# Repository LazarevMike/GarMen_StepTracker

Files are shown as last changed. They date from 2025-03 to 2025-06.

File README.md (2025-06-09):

# GarMen StepTracker

Code for step tracker for Embedded Mechatronic Systems (Autumn 2025) at UTS.  
Using ESP32S3 Mini and a custom-designed PCB in Altium Designer.
Programmed on C++ in Arduino IDE

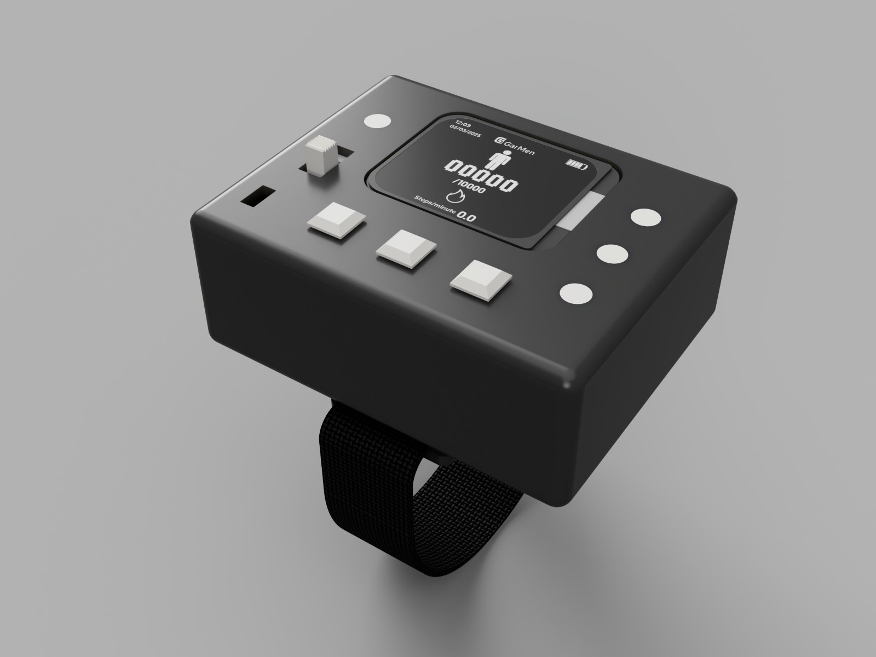
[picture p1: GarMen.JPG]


---

## 📌 Project Overview

This repository contains the Arduino code, simulation files and MCAD for the **Step Tracker System** using custom designed PCB, featuring ESP32S3 Mini ship and ADXL335 accelerometer.
The system counts steps, identifies walking pace, monitors heart rate and calories, and provides a clean user interface using an LCD screen.

---

## 🚀 Features

- **Step Counting**: Accurate detection using analog acceleration.
- **Pace Detection**: Classifies movement as Idle, Walk, or Run.
- **Heart Rate Monitoring**: Connects to BLE HR sensors (e.g., Polar H10).
- **Calories Burned Calculation**: Uses Zillman formula for accurate kcal estimation.
- **User Interface**:
  - LCD screen with different display modes (Steps / Stats).
  - Bluetooth connectivity status, battery level (optional), and timer.
- **Self-Test Protocol**: Validates ADXL335 using the ST pin.
- **Static Acceleration Calibration**: Calibrates ±X, ±Y, ±Z axes using known gravity values.
- **Dual Power Input**: Runs from DC barrel jack or battery.
- **Signal Conditioning**: Filters analog signals before ADC sampling.
- **BNC Output**: Clean analog Z-axis output for lab validation.

---

## 📦 Required Libraries

Before compiling and uploading, make sure the following Arduino libraries are installed:

| Library | Purpose |
|---|---|
| [`Adafruit GFX Library`](https://github.com/adafruit/Adafruit-GFX-Library) | Core graphics support for LCD display |
| [`Adafruit ST7735 and ST7789 Library`](https://github.com/adafruit/Adafruit-ST7735-Library) | Driver for 1.69" TFT LCD |
| [`TFT_eSPI`](https://github.com/Bodmer/TFT_eSPI) | High-performance display driver |
| [`NimBLE-Arduino`](https://github.com/h2zero/NimBLE-Arduino) | Efficient BLE (Bluetooth Low Energy) support for ESP32 |

> 🛠️ **Install these using**:  
> `Arduino IDE → Sketch → Include Library → Manage Libraries`  
> Or manually from GitHub into your `libraries` folder.

---

## 📁 Folder Structure

```text
code/Step_Tracker/
│
├── Step_Tracker.ino               # Main Arduino sketch (initializes and runs StepTracker)
│
├── StepTracker.cpp/.h            # Core system controller (coordinates sensors, UI, and states)
├── StepCounter.cpp/.h            # Step detection, step rate, and pace estimation
├── CaloriesCalculator.cpp/.h     # Calorie calculation based on heart rate and step data
├── HeartRateMonitor.cpp/.h       # BLE heart rate monitor interface and data parser
├── ADXL335.cpp/.h                # Accelerometer driver (data reading, calibration, self-test)
├── Clock.cpp/.h                  # Tracks elapsed runtime using millis()
│
├── Button.cpp/.h                 # Debounced button input handler
├── Led.cpp/.h                    # LED driver with state control 
├── Lcd.cpp/.h                    # LCD display manager using Adafruit ST7789
├── UserInterface.cpp/.h          # High-level UI controller (button handling, display updates)
├── DisplayState.h                # Enum for UI display modes (Steps, Stats, Calibration, SelfTest)
└── media/                        # Folder for images, fonts, or other display assets

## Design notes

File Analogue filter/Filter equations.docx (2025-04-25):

# Solving second order analogue filter

Second order polynomial:

P(s)= s^2 +1.414s+1

Coefficients:

a_1 =1.414, a_0 =1

Substitutions:

s=j2πω, ωc=2πfc, a_1 =1/Q, √(a_0)=FSF

Hence,

Q=0.707, FSF=1

For filter with gain K=1, equations from Texas Instruments:

FSF×f_c =1/(2πRC√(mn)), Q= (√(mn))/(m+1) where R_1 =mR, R_2 =R, C_1 =C, C_2 =nC

Solving for ratio of m and n

0.707= (√(mn))/(m+1)

0.707^2 =(mn)/(m^2 +2m+1)

0.707^2 m^2 +(2×0.707^2 -n)m+0.707^2 =0

m= (n-2×0.707^2 + √((2×0.707^2 -n)^2 -4×0.707^4))/(2×0.707^2)

The above gives us a graph for n to m ratio. Here we are free to pick any convenient ratio for the filter.

Choose n=2, m=1

Desired f_c =25Hz

Substituting in the equations from Texas Instruments to obtain C and R near standard values:

25= 1/(√2×2πRC)

As R is predetermined by internal resistance on each output of ADXL:

Choose R=32K (standard value)

C=1/(√2 ×25×2π×32×10^3)=0.1407×10^(-6) ≈0.15μF (standard value as well)

Results: R_1 =32K, R_2 =32K, C_1 =0.15μF, C_2 =0.33μF

Check the actual cutoff frequency f_c

f_c = 1/(2π×32×10^3 ×√(0.15×0.33)×10^(-6))=22.35 Hz - a bit lower than expected f_c

Let’s adjust value for R_2 as we can choose it freely as long as Q stays around 0.707

Try: R_2 =27K

Check for Q

Q= (√(32×10^3 ×27×10^3 ×0.15×10^(-6) ×0.33×10^(-6)))/((32+27)×10^3 ×0.15×10^(-6))=0.739 (expected 0.707)

As Q is so far off, behaviour of filter might be altered. That calls for reworking coefficients m and n

Choose m=3.95, n=3.1 , since it is easy to find capacitors for such ratio n

As it is predetermined by ADXL that R_1 =32K

R_2 =(R_1)/m=(32×10^3)/3.95 =8.10 ×10^3 ≈8.2K (table value)

Compute actual m

m=32/8.2=3.90

Now, calculate C for chosen f_c

C=1/(√(3.1×3.90) ×25×2π×8.2×10^3)=2.23×10^(-7) ≈0.22μF (table value)

C_2 =nC=0.22×10^(-6) ×3.1=0.682×10^(-6) ≈0.68μF (table value)

Results: R_1 =32K, R_2 =8.2K, C_1 =0.22μF, C_2 =0.68μF

Check for actual f_c

f_c = 1/(2π×√(32×8.2×0.22×0.68)×10^3 ×10^(-6))=25.4Hz

Taking into account tolerance of 15% on R_1 , f_c is expected to be within 23.7 – 27.6Hz

Finally, check for actual Q

Q= (√(32×10^3 ×8.2×10^3 ×0.22×10^(-6) ×0.68×10^(-6)))/((32+8.2)×10^3 ×0.22×10^(-6))= 0.708 - very close to expected 0.707

Taking into account tolerance of 15% on R_1 , Q is expected to be within 0.679 – 0.742

To negate very low tolerance on R_1 , it was decided to not use the resistor from ADXL and rather place another 32K resistor with higher tolerance, separated from ADXL using buffer amplifier.

Appendix:

A. Graph for n and m

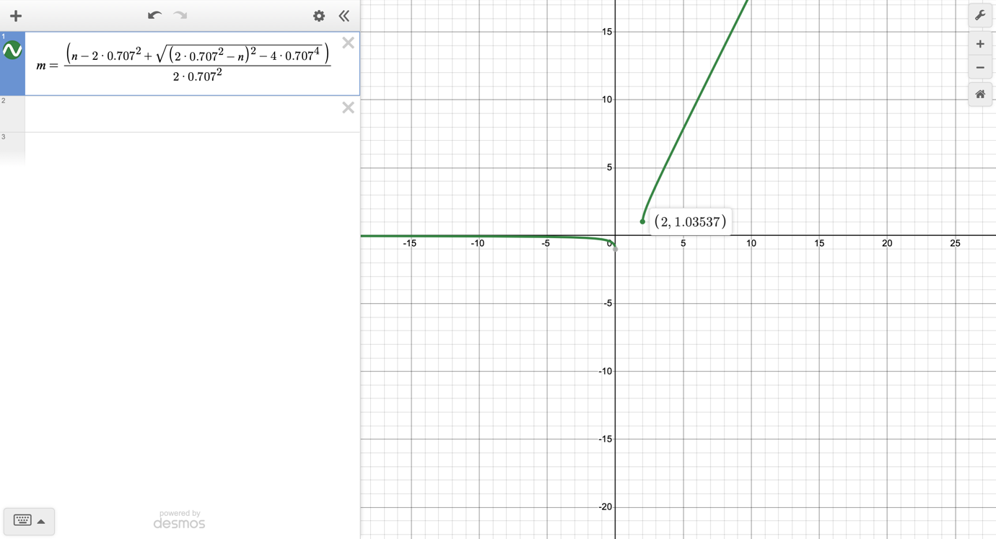
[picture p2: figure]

B. Another trial for m and n:

Choose n=2.2, m = 1.87

Hence R1 = 32K (from datasheet)

R2 = 17.65 ~ 18K

Calculate C for cutoff frequency 25Hz

C = 0.17 microF – not table value. Try again

Can be used if fc is changed to 29Hz or 18-19Hz

C. Calculations brief (for slides)  Second order polynomial:

P(s)= s^2 +1.414s+1

From the coefficients of the polynomial:

Q=0.707, FSF=1

For filter with gain K=1, equations from Texas Instruments:

FSF×f_c =1/(2πRC√(mn)), Q= (√(mn))/(m+1) where R_1 =mR, R_2 =R, C_1 =C, C_2 =nC

Solving for ratio of m and n we get the graph for m

m= (n-2×0.707^2 + √((2×0.707^2 -n)^2 -4×0.707^4))/(2×0.707^2)

Choose m=3.95, n=3.1 , since it is easy to find capacitors for such ratio n

After choosing R_1 =32K and calculating the rest of components:

R_1 =32K, R_2 =8.2K, C_1 =0.22μF, C_2 =0.68μF

Check for actual f_c

f_c = 1/(2π×√(32×8.2×0.22×0.68)×10^3 ×10^(-6))=25.4Hz

Finally, check for actual Q

Q= (√(32×10^3 ×8.2×10^3 ×0.22×10^(-6) ×0.68×10^(-6)))/((32+8.2)×10^3 ×0.22×10^(-6))= 0.708

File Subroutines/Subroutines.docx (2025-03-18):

Subroutines

Self-test subroutine

//While ADXL is stationary

Function ADXLSelfTest(ST_pin, X_pin, Y_pin, Z_pin) {

Write digital low to ST_pin

Pause 100ms

Record base values from X_pin, Y_pin, Z_pin

Write digital high to ST_pin

Pause 100ms

Record new values from X_pin, Y_pin, Z_pin

Write digital low to ST_pin

Calculate difference between base values and new values

If difference is greater than 0.3V (ADC value 4096 * 0.3/3.3 = 370) {

Output to serial “Self-test passed”

Return true

}

Else {

Output to serial “Self-test not passed”

Return false

}

}

Calibration subroutine

//After step tracker is mounted on the shoulder

Function ADXLCalibration(X_pin, Y_pin, Z_pin) {

Pause 5s

Record base values from X_pin, Y_pin, Z_pin

Pause 5s

Blink LEDs to indicate that used should start walking

//While user is walking

For the next 10s {

Record maximum values from X_pin, Y_pin, Z_pin

}

Blink LEDs twice to indicate that calibration is complete

Subtract base values from maximum values to get differences

Divide difference values by 1.4

Return an array of base values and difference values

//These values should be used in the main script for comparison to detect steps

Step tracker subroutine

//After calibration is complete

Function stepTracking()

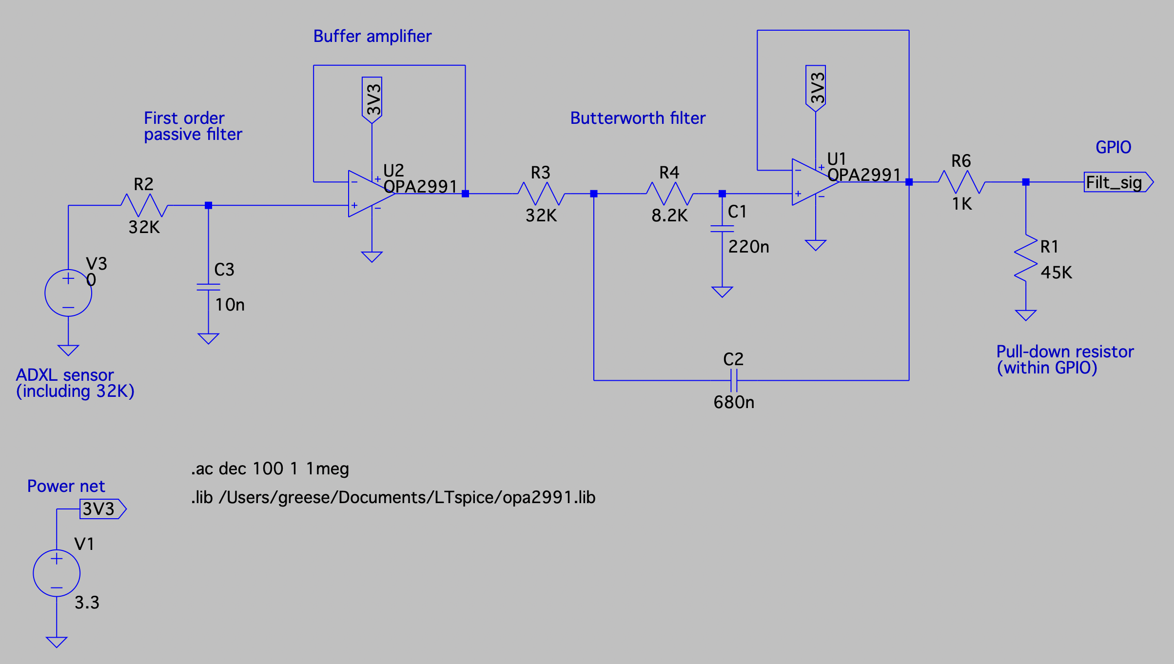
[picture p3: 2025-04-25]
Simulations/Analogue filter/Real model/Schematic.png

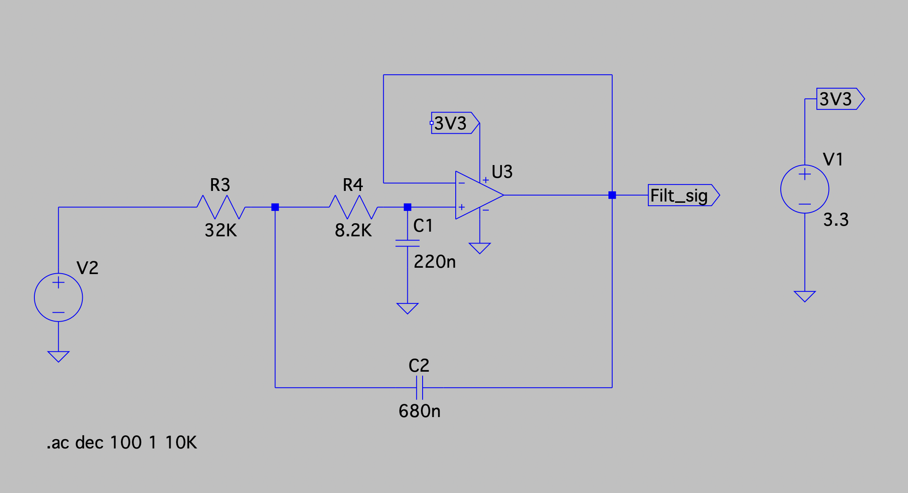
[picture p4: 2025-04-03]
Simulations/Analogue filter/Ideal model/Schematic.png

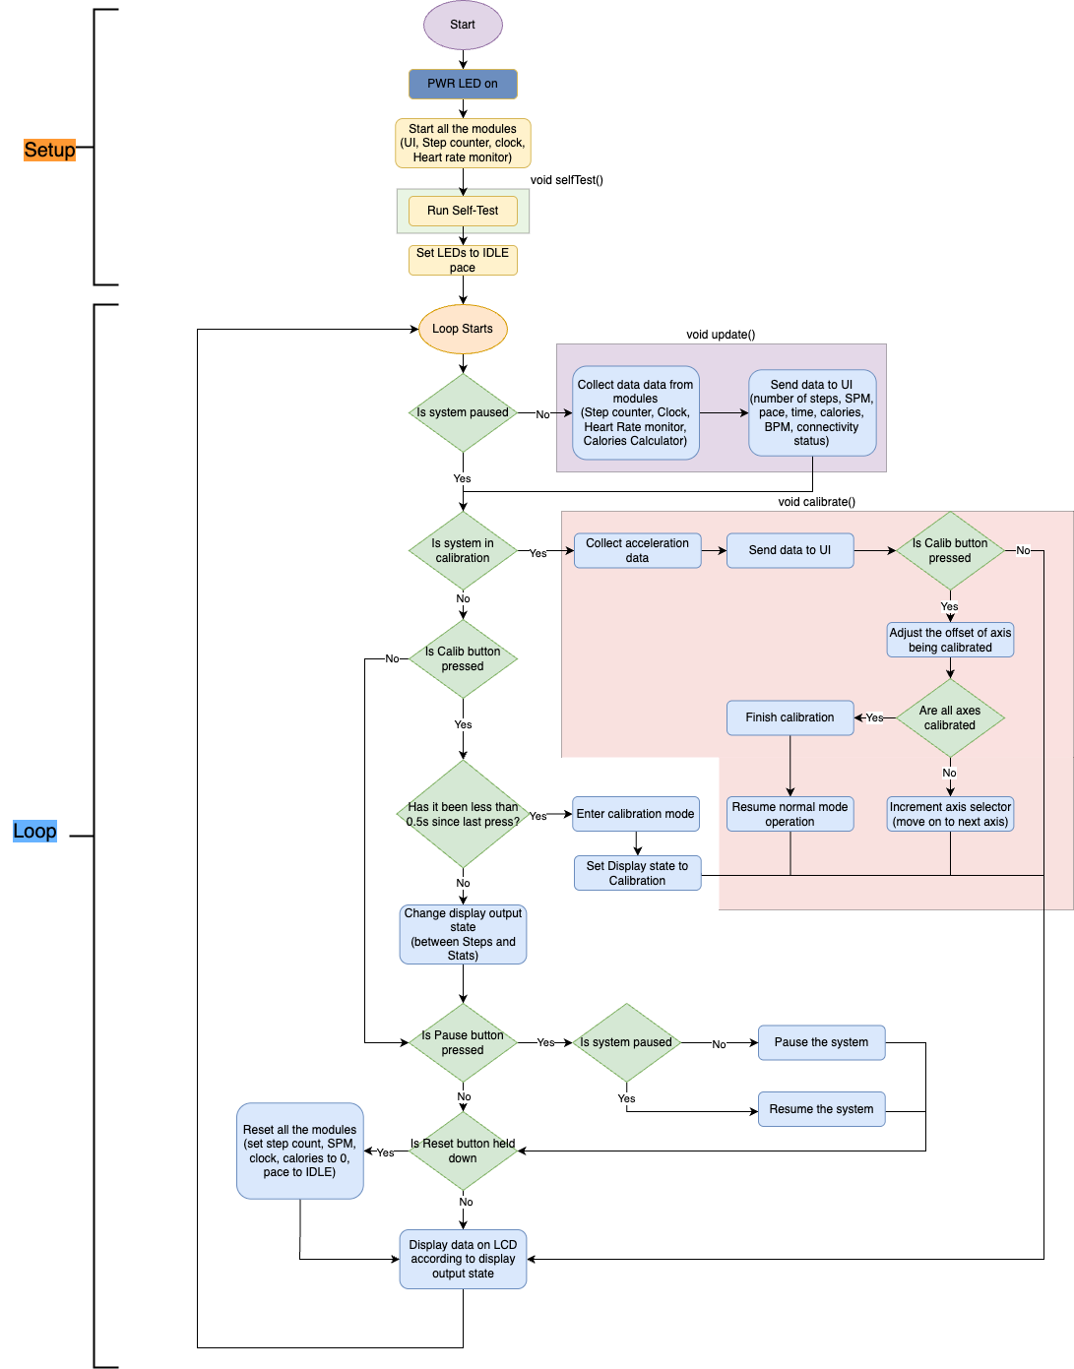
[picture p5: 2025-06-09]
Diagrams/Main flowchart.png

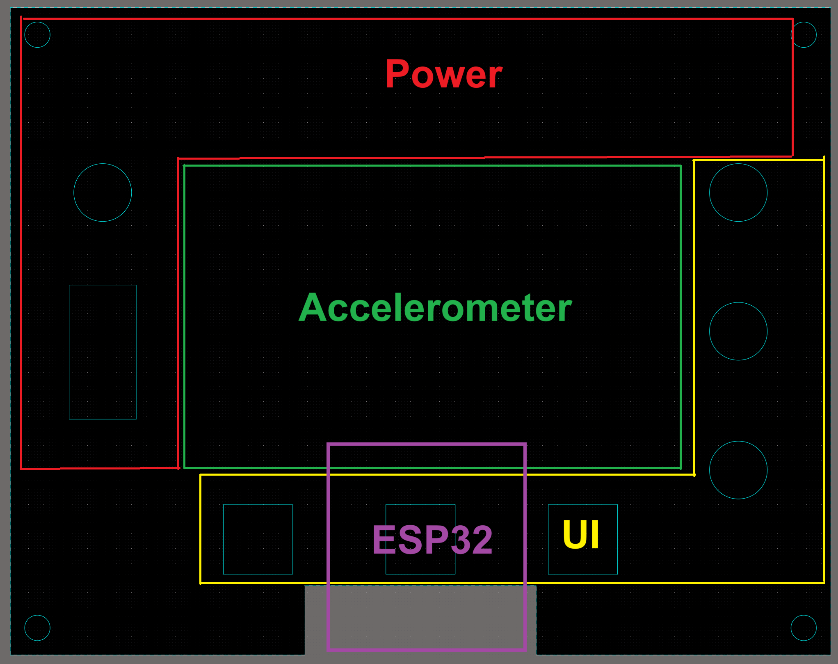
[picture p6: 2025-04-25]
Diagrams/PCB layout.png

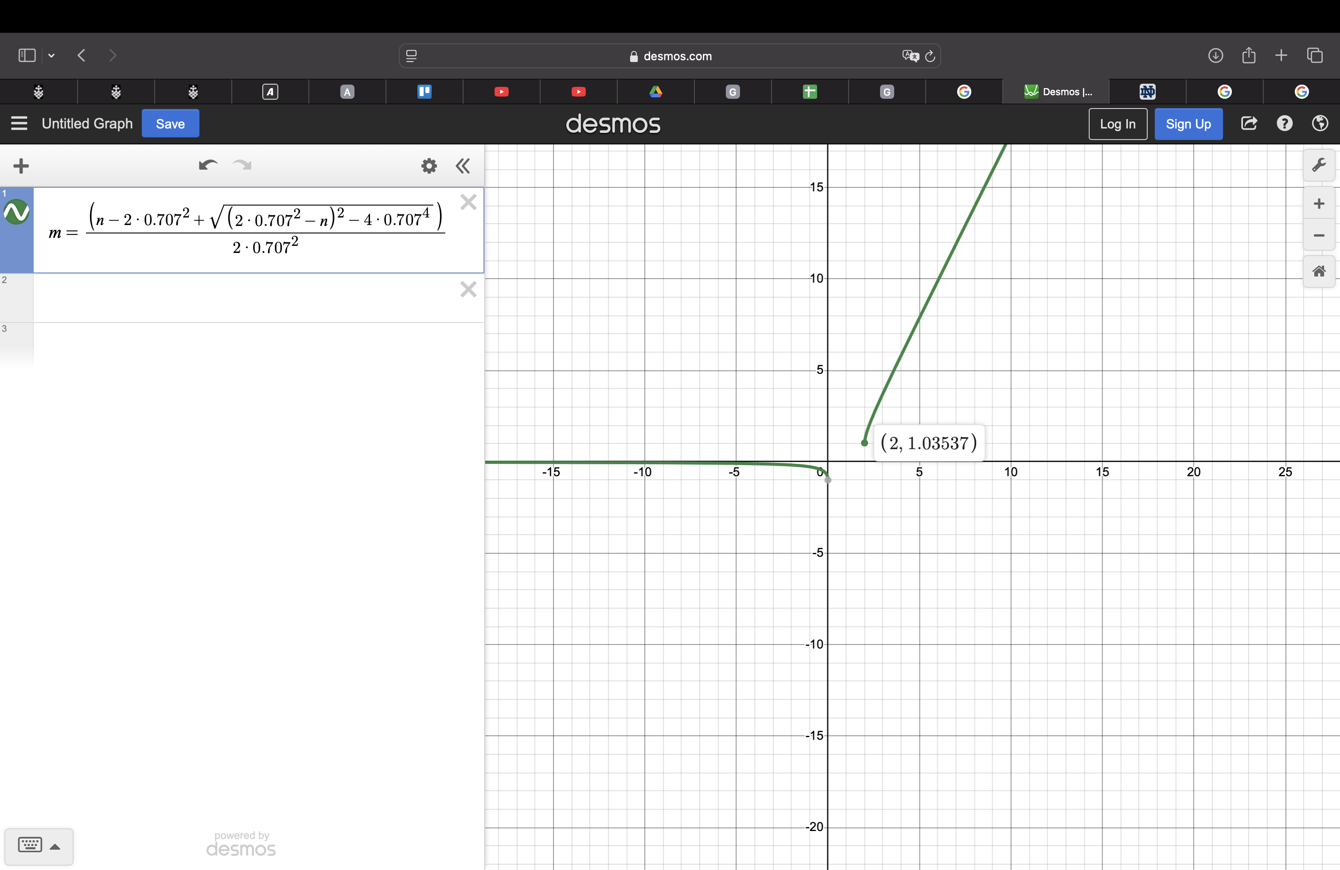
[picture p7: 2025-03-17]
Analogue filter/Graph.png

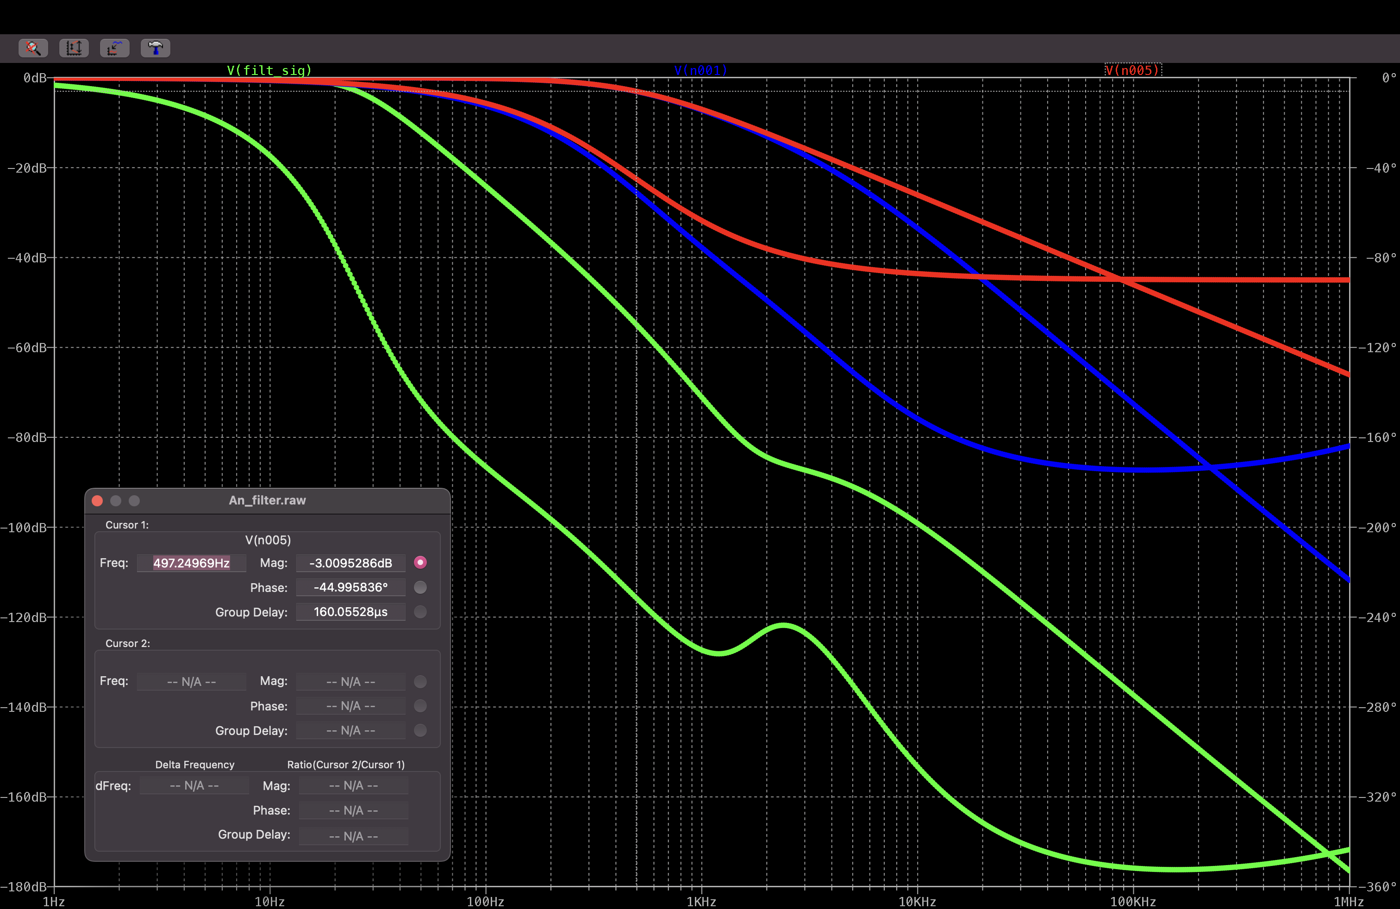
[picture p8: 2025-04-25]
Simulations/Analogue filter/Real model/Cutoff passive.png

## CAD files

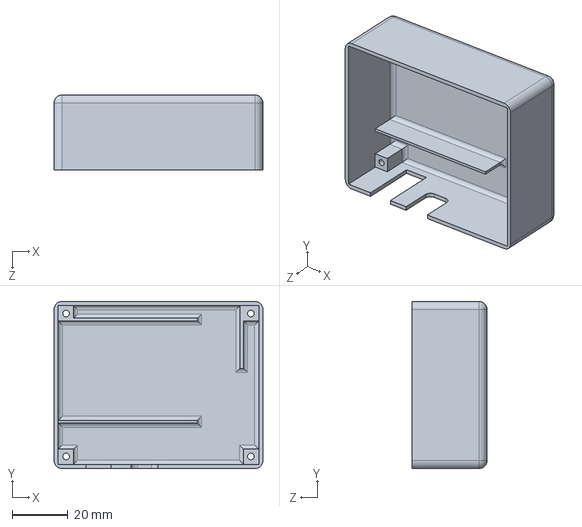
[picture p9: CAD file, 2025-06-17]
SolidWorks/Enclosure design/Main Case.SLDPRT
75.0 x 60.0 x 27.0 mm

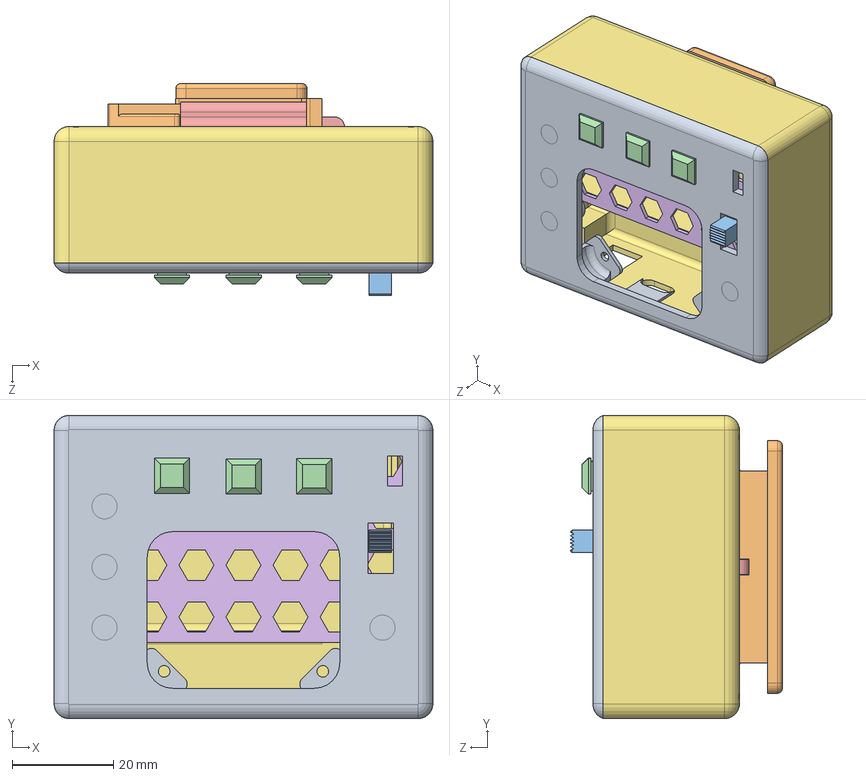
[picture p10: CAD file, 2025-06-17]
SolidWorks/Enclosure design/StepStracker Assembly.SLDASM
75.0 x 60.0 x 41.9 mm
Main Case
Mid plate
Universal connector
Button Cap x 3
Switch cap
Buckle
Top Cover

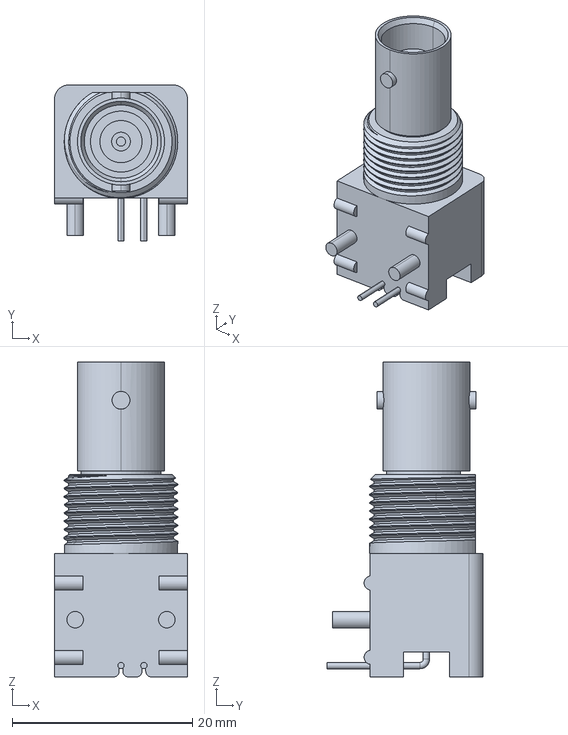
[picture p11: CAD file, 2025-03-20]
SolidWorks/Components/BNCConnector.stp
14.8 x 17.3 x 34.9 mm

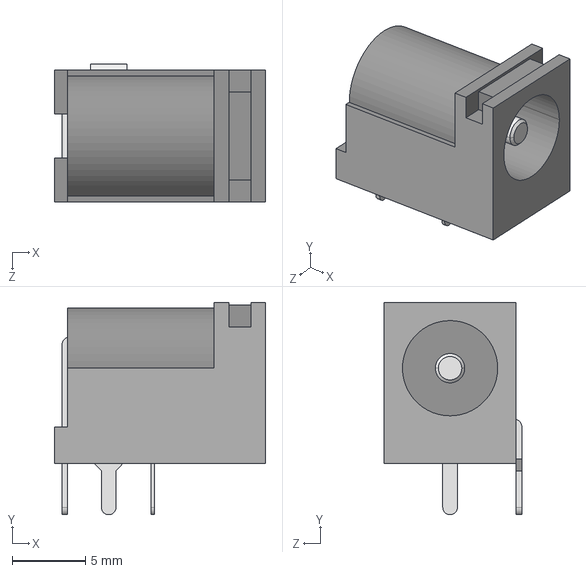
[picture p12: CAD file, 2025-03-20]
SolidWorks/Components/PowerBarrelConnector/BarrelJackConnector.step
14.4 x 14.5 x 9.40 mm

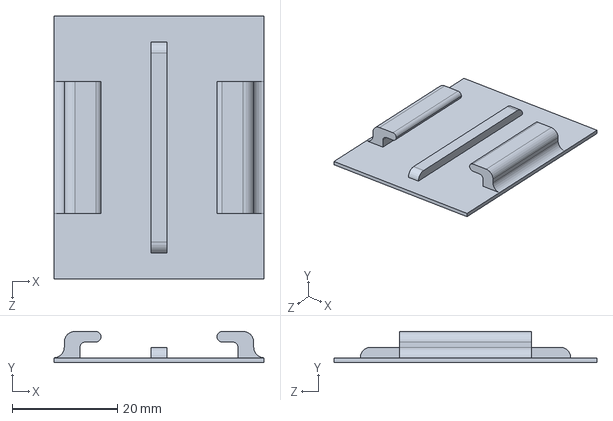
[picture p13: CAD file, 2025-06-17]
SolidWorks/Enclosure design/Universal connector.SLDPRT
39.9 x 5.90 x 49.9 mm

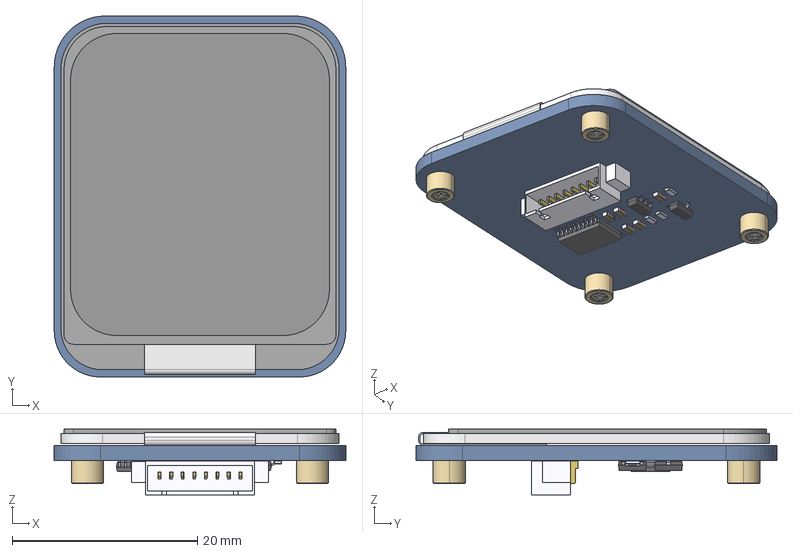
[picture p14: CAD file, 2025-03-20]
SolidWorks/Components/1_69inch-lcd-module.stp
31.5 x 39.0 x 7.11 mm
1_69INCH-240X280-LCD
1_69INCH_LCD_MODULE-PCBA
STUDS-M2XH2_5 x 4

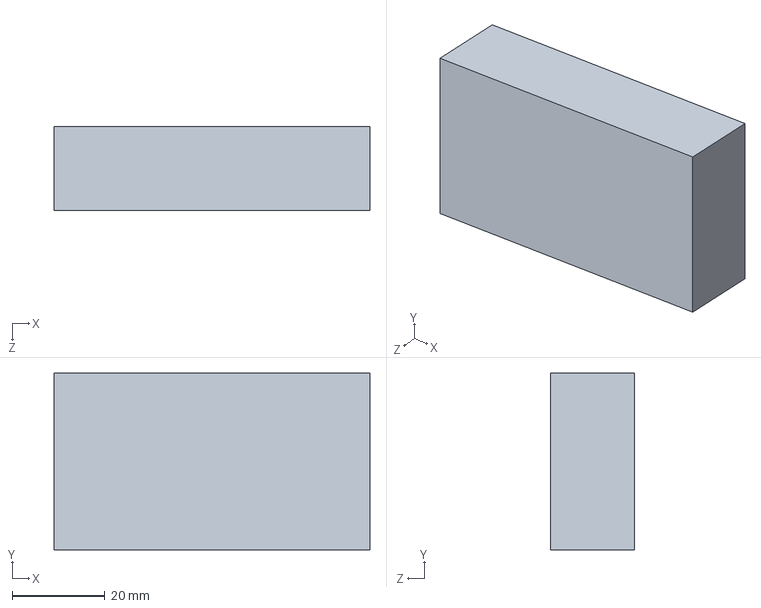
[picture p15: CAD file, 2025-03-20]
SolidWorks/Components/7.4VBattery.STEP
68.0 x 38.0 x 18.0 mm

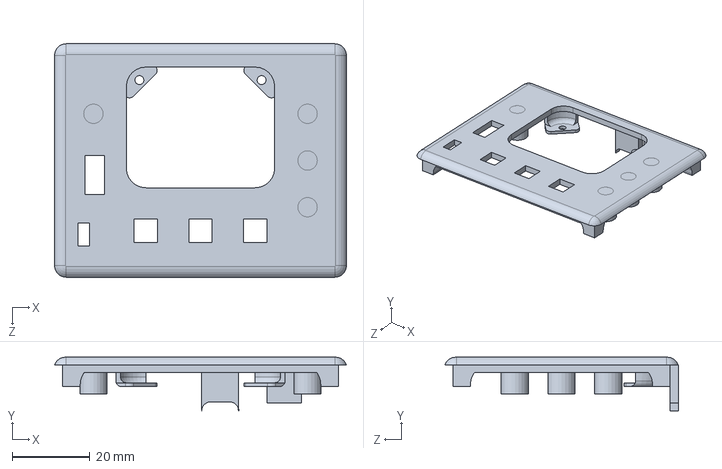
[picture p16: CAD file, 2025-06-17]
SolidWorks/Enclosure design/Top Cover.SLDPRT
75.0 x 13.8 x 60.0 mm

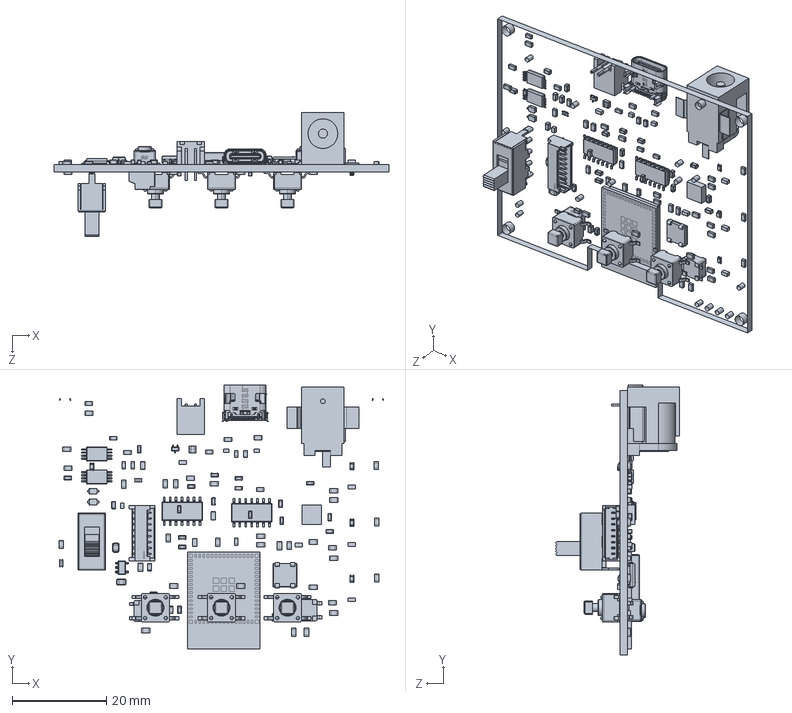
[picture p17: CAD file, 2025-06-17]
SolidWorks/Enclosure design/PCB_steptracker.SLDPRT
71.0 x 57.2 x 26.3 mm

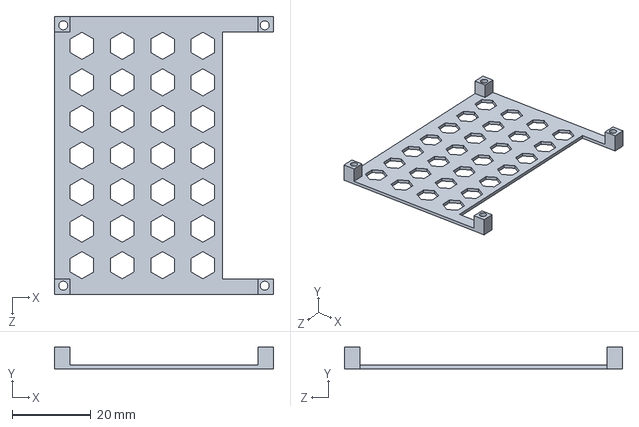
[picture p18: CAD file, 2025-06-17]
SolidWorks/Enclosure design/Mid plate.SLDPRT
55.8 x 5.50 x 70.8 mm

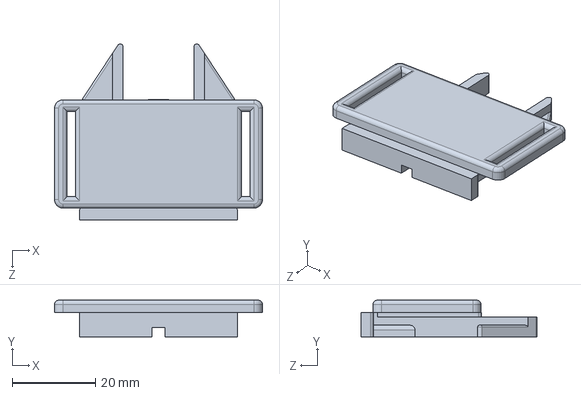
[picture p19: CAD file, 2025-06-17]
SolidWorks/Enclosure design/Buckle.SLDPRT
50.0 x 8.80 x 42.4 mm

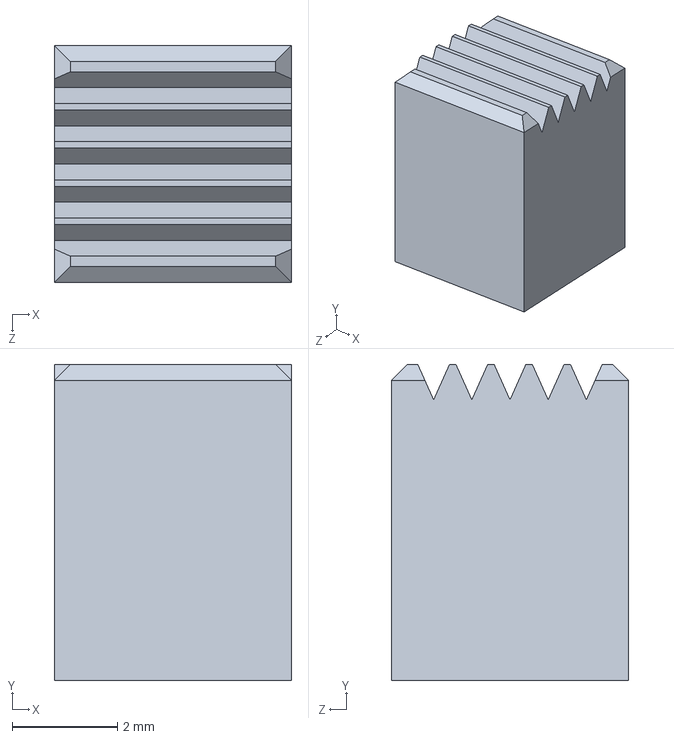
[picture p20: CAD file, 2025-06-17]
SolidWorks/Enclosure design/Switch cap.SLDPRT
4.50 x 6.00 x 4.50 mm

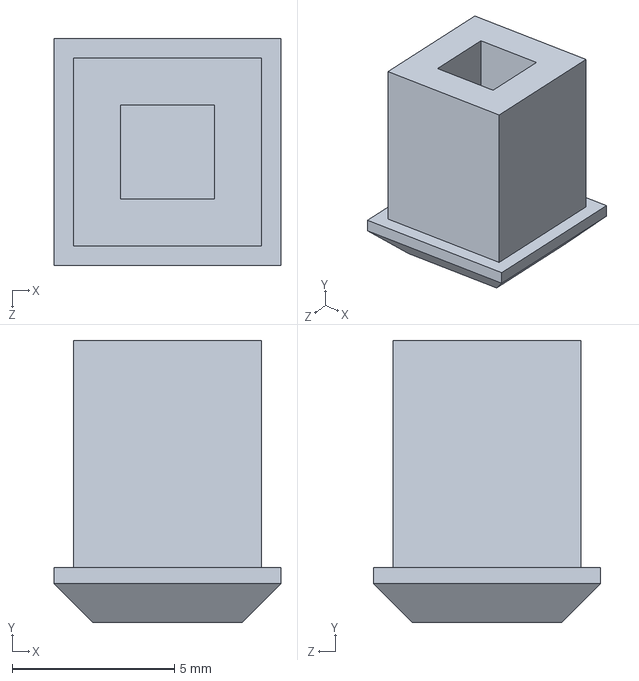
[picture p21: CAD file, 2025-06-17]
SolidWorks/Enclosure design/Button Cap.SLDPRT
7.00 x 8.70 x 7.00 mm

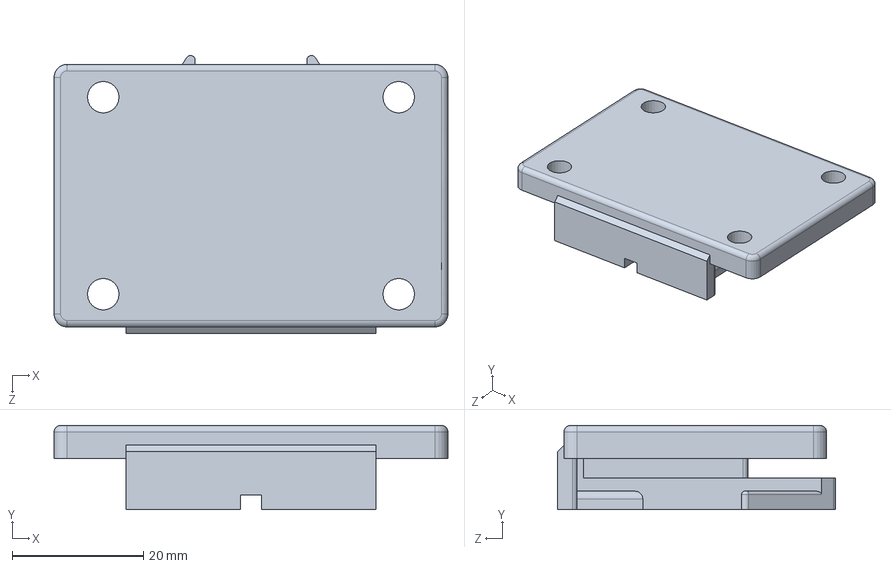
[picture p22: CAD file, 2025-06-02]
SolidWorks/Enclosure design/Mounting Buckle.SLDPRT
60.0 x 12.8 x 42.4 mm

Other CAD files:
SolidWorks/Enclosure design/1_69inch-lcd-module.SLDASM
SolidWorks/Enclosure design/PCB.SLDPRT
SolidWorks/Enclosure design/BNCConnector.SLDPRT
SolidWorks/Enclosure design/Battery.SLDPRT
SolidWorks/Components/Amphenol ICC (FCI)/20021221-00006C4LF.step
SolidWorks/Enclosure design/20021221-00006C4LF.SLDPRT
SolidWorks/Enclosure design/BarrelJackConnector.SLDPRT
SolidWorks/Enclosure design/Drawings/StepStracker Assembly.SLDDRW
SolidWorks/Enclosure design/Drawings/Top Cover.SLDDRW

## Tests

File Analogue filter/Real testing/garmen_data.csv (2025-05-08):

#Digilent WaveForms Network Analyzer - Bode
#Device Name: Discovery3
#Serial Number: SN:210415BCB4FB
#Date Time: 2025-05-06 14:46:24.910
#Start: 10 Hz
#Stop: 5000 Hz
#Steps: 151
#Wavegen: Wavegen C1
#Amplification: 1 X
#Settle: 10 ms
#MinPeriods: 16
#Channel: Channel 1
#Range: 5.19526 V
#Offset: 0.000309259 V
#Relative: no
Frequency (Hz) | Channel 1 Magnitude (dB)
10.00000000000001 | -0.2790251977869876
10.42300949424216 | -0.3030347177211944
10.86391269170621 | -0.3288130672549798
11.32346651302716 | -0.3580111438277471
11.80245989730152 | -0.3907812594463873
12.3017151564986 | -0.4284998944964031
12.82208938716475 | -0.4705111509610605
13.36447594184397 | -0.51956497628347
13.92980596274105 | -0.5751479845721507
14.51904998026008 | -0.6377328632870954
15.13321957916271 | -0.7093264217489261
15.77336913520643 | -0.7895391196473458
16.44059762524425 | -0.8792304550341733
17.1360505138936 | -0.9820678552899609
17.8609217200126 | -1.099874597101095
18.61645566636071 | -1.229982370940561
19.40394941596158 | -1.377710906480503
20.2247548988362 | -1.545833553534943
21.08028123292901 | -1.731537745959306
21.97199714321139 | -1.938381576497504
22.90143348311534 | -2.168495518726666
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

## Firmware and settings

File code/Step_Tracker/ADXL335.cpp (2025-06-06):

#include "ADXL335.h"
#include "Arduino.h"

ADXL335::ADXL335() : X_PIN_(8), Y_PIN_(13), Z_PIN_(9), ST_PIN_(34), 
X_ADC_OFFSET_(DEFALUT_ADC_OFFSET_), Y_ADC_OFFSET_(DEFALUT_ADC_OFFSET_), Z_ADC_OFFSET_(DEFALUT_ADC_OFFSET_) {
  pinMode(X_PIN_, INPUT);
  pinMode(Y_PIN_, INPUT);
  pinMode(Z_PIN_, INPUT);
  pinMode(ST_PIN_, OUTPUT);
  triggerSt(false);
}

int ADXL335::readX() {
  return analogRead(X_PIN_);
}

int ADXL335::readY() {
  return analogRead(Y_PIN_);
}

int ADXL335::readZ() {
  return analogRead(Z_PIN_);
}

void ADXL335::adjustOffsetX() {
  X_ADC_OFFSET_ = ((1.65 - SENSITIVITY_) / 3.3) * 4095 - readX();
}

void ADXL335::adjustOffsetY() {
  Y_ADC_OFFSET_ = ((1.65 + SENSITIVITY_) / 3.3) * 4095 - readY();
}
    
void ADXL335::adjustOffsetZ() {
  //Because adjusting on -g
  Z_ADC_OFFSET_ = ((1.65 - SENSITIVITY_) / 3.3) * 4095 - readZ();
}

float ADXL335::readAccelX() {
  // By hardware x is inverted
  return -convertADCtoAccel(readX() + X_ADC_OFFSET_);
}

float ADXL335::readAccelY() {
  return convertADCtoAccel(readY() + Y_ADC_OFFSET_);
}
    

float ADXL335::readAccelZ() {
  return convertADCtoAccel(readZ() + Z_ADC_OFFSET_);
}

void ADXL335::triggerSt(bool new_state) {
  st_state_ = new_state;
  //Inverted because by design st pin driver is active low
  digitalWrite(ST_PIN_, !st_state_);
}

bool ADXL335::selfTest() {
  float x1 = readAccelX();
  float y1 = readAccelY();
  float z1 = readAccelZ();
  triggerSt(true);
  delay(300);
  float x2 = readAccelX();
  float y2 = readAccelY();
  float z2 = readAccelZ();
  bool outcome = (x2 - x1 > -0.9 && y2 - y1 > 0.9 && z2 - z1 > 1.5);
  triggerSt(false);
  return outcome; 
}

bool ADXL335::getStState() {
  return st_state_;
}

float ADXL335::convertADCtoAccel(int adc_reading) {
  float voltage = (adc_reading)/4095.0 * 3.3;
  return (voltage - 1.65) / SENSITIVITY_;
}

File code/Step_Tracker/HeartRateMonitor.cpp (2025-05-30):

#include "HeartRateMonitor.h"

#define HEART_RATE_SERVICE_UUID        "180D"
#define HEART_RATE_MEASUREMENT_UUID   "2A37"

// Static pointer used to reference the class instance inside the static callback
HeartRateMonitor* HeartRateMonitor::instancePtr = nullptr;

/*
   Constructor initializes all internal state variables.
*/
HeartRateMonitor::HeartRateMonitor()
    : advDevice(nullptr),
      client(nullptr),
      latestBPM(0),
      newBPMAvailable(false),
      connected(false),
      doConnect(false) {}

/*
   Static notification callback for BLE heart rate data.
   Extracts BPM value from received data and stores it for printing in the main loop.
*/
void HeartRateMonitor::heartRateNotifyCB(NimBLERemoteCharacteristic* pChar, uint8_t* data, size_t length, bool isNotify) {
    if (length >= 2 && instancePtr != nullptr) {
        uint8_t flags = data[0];
        uint16_t bpm = (flags & 0x01) == 0
            ? data[1]                            // 8-bit BPM
            : (data[1] | (data[2] << 8));        // 16-bit BPM

        instancePtr->latestBPM = bpm;
        instancePtr->newBPMAvailable = true;
    }
}

/*
   Iterates over scan results to find a device advertising the Heart Rate Service.
   Stores reference to the matching device and stops scanning.
*/
void HeartRateMonitor::handleScanResults() {
    NimBLEScanResults results = NimBLEDevice::getScan()->getResults();

    for (int i = 0; i < results.getCount(); i++) {
        const NimBLEAdvertisedDevice* device = results.getDevice(i);

        if (device->isAdvertisingService(NimBLEUUID(HEART_RATE_SERVICE_UUID))) {
            Serial.println("Found device with Heart Rate Service.");
            advDevice = const_cast<NimBLEAdvertisedDevice*>(device);
            doConnect = true;
            NimBLEDevice::getScan()->stop();
            break;
        }
    }
}

/*
   Establishes BLE connection to the discovered device and subscribes to the
   heart rate characteristic for notifications.

   Returns true on successful connection and subscription, false otherwise.
*/
bool HeartRateMonitor::connect() {
    client = NimBLEDevice::createClient();

    if (!client->connect(advDevice)) {
        Serial.println("Failed to connect.");
        NimBLEDevice::deleteClient(client);
        return false;
    }

    Serial.println("Connected to device.");

    NimBLERemoteService* service = client->getService(HEART_RATE_SERVICE_UUID);
    if (!service) {
        Serial.println("Heart Rate Service not found.");
        client->disconnect();
        return false;
    }

    NimBLERemoteCharacteristic* characteristic = service->getCharacteristic(HEART_RATE_MEASUREMENT_UUID);
    if (!characteristic || !characteristic->canNotify()) {
        Serial.println("Heart Rate Characteristic not found or notifications not supported.");
        client->disconnect();
        return false;
    }

    if (!characteristic->subscribe(true, heartRateNotifyCB)) {
        Serial.println("Subscription to notifications failed.");
        client->disconnect();
        return false;
    }

    Serial.println("Subscribed to heart rate notifications.");
    connected = true;
    return true;
}

/*
   Initializes BLE stack, sets scan parameters, and starts scanning for BLE heart rate monitors.
   Also stores instance pointer to enable use of static callback.
*/
void HeartRateMonitor::begin() {
    instancePtr = this;

    NimBLEDevice::init("ESP32-HRM");

    NimBLEScan* scan = NimBLEDevice::getScan();
    scan->setActiveScan(true);     // Request additional advertising data
    scan->setInterval(45);         // How frequently to scan (in 0.625 ms units)
    scan->setWindow(15);           // How long to scan during each interval
    scan->start(0);                // 0 = scan indefinitely
}

/*
   This function should be called repeatedly in the main loop.
   It manages device discovery, connection attempts, and safely prints BPM when new data is available.
*/
void HeartRateMonitor::update() {
    // Continue processing scan results if not yet connected
    if (!connected) {
        handleScanResults();
    }

    // Attempt connection if a valid device was found
    if (doConnect && !connected) {
        doConnect = false;
        if (!connect()) {
            Serial.println("Connection failed. Restarting scan...");
            NimBLEDevice::getScan()->start(0);
        }
    }

    // Print latest heart rate reading, ensuring safe access to shared data
    if (newBPMAvailable) {
        noInterrupts();
        uint16_t bpmToPrint = latestBPM;
        newBPMAvailable = false;
        interrupts();

        Serial.printf("Heart Rate (BPM): %d\n", bpmToPrint);
    }
}

// Returns latest HR BPM
int HeartRateMonitor::getLatestBPM() const {
    return latestBPM;
}

// Returns connection status for HR monitor
bool HeartRateMonitor::isConnected() const {
    return connected;
}

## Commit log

2025-03-07 added Amphenol ICC (FCI) solidworks files
    [20021221-00006C4LF.step]
2025-03-07 Sourced main components 3D models
    [1_69inch-lcd-module.stp, BNCConnector.stp, BarrelJackConnector.step]
2025-03-07 Added sample code for Display and a python file to convert image to uint8_t image
2025-03-09 Battery model added
    [7.4VBattery.STEP]
2025-03-11 Updated diagram. New cut-off freq
2025-03-17 Analogue filter solved
2025-03-18 Added subroutines, changed R and C for filter
2025-03-20 Enclosure design updates
    [1_69inch-lcd-module.SLDASM, 1_69inch-lcd-module.stp, 20021221-00006C4LF.SLDPRT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]
2025-03-24 Reworked filter to accomodate for internal resistor of adxl
2025-03-24 Mechanical enclosure changes
    [Main Case.SLDPRT, Mid plate.SLDPRT, PCB.SLDPRT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]
2025-03-31 Added simulation results for self-test and analogue filter
2025-04-03 Enclosure changes
    [Buckle.SLDPRT, Main Case.SLDPRT, Mid plate.SLDPRT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]
2025-04-07 Added resistor to sim schematic
2025-04-25 solidworks files update
    [Main Case.SLDPRT, Top Cover.SLDPRT]
2025-05-08 Added some code file+ updated solidworks models
    [Main Case.SLDPRT, Mid plate.SLDPRT, Top Cover.SLDPRT]
2025-05-08 Added results for frequency sweep of analogue filter
    [garmen_data.csv]
2025-05-12 Added structure fot UI. Added classes for LEDs and Buttons with basic functionality
2025-05-12 Added buttons
2025-05-13 Updated buttons, added test code for buttons in UI
2025-05-15 enclosure design update
    [Buckle.SLDPRT, Button Cap.SLDPRT, Main Case.SLDPRT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]
2025-05-18 Finished Enclosure design
    [Switch cap.SLDPRT, Top Cover.SLDPRT]
2025-05-29 updated 3d models
    [Switch cap.SLDPRT, Top Cover.SLDPRT]
2025-05-30 added heart rate monitor code + edited solidworks models
    [Buckle.SLDPRT, Mid plate.SLDPRT, Switch cap.SLDPRT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]
2025-05-30 changed calories calculation + added comments to buttons
2025-05-30 made working UI
    Step screen ui, and HR and calories UI done
    [Buckle.SLDPRT, Button Cap.SLDPRT]
2025-06-02 minor changes enclosure CAD
    [Buckle.SLDPRT, Mounting Buckle.SLDPRT]
2025-06-02 added calibration screen
2025-06-02 finish calibration screen
2025-06-02 finished adding calibration screen
2025-06-02 some changes for solidworks + screen fix
    [Top Cover.SLDPRT]
2025-06-02 display switching
2025-06-02 Calibration complete, time complete, everything is good
2025-06-03 Hard coded calibration for now
2025-06-03 Fixed calibration
2025-06-06 Added holding buttons feature
2025-06-09 Added flowchart, created the flowrchart outlining main architecture
2025-06-16 cad changes
    [1_69inch-lcd-module.SLDASM, Buckle.SLDPRT, Button Cap.SLDPRT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]
